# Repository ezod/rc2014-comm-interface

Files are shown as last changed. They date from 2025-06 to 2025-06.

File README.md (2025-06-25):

# RC2014 Communication Interface Module

This is a serial communication module for [RC2014](https://rc2014.co.uk/) computers providing an easy way to switch dual serial port connections between RS232, FTDI, and an ESP01 module.

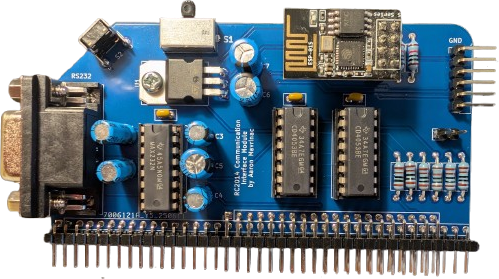
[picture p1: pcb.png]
pcb


| Switch Position | Port A | Port B |
|---|---|---|
| left | FTDI | ESP01  |
| middle | RS232  | ESP01  |
| right | RS232  | FTDI |

These configuration options allow you to switch between a PC and a serial terminal as the main console, connect either to an ESP01 modem using [Zimodem](https://github.com/bozimmerman/Zimodem) or similar, and do XMODEM transfers over FTDI from a serial terminal.

## Bill of Materials

| Reference | Part |
|---|---|
| U1 | LD1117V33 |
| U2 | MAX232N |
| U3-U4 | CD4053B |
| R1-R6 | 1K resistor |
| R7 | 3.3K resistor |
| R8 | 4.7K resistor |
| R9-R10  | 10K resistor |
| C1-C4 | 1uF electrolytic capacitor |
| C5-C6 | 10uF electrolytic capacitor |
| C7 | 47uF electrolytic capacitor |
| C8-C10  | 0.1uF disc/MLCC capacitor |
| S1 | EG2315 DP3T slide switch |
| S2 | right angle tactile switch |
| J1 | 1x6 0.1" right angle pin header  |
| J2 | DE9 female socket |
| J3 | 2x8 0.1" straight pin socket |
| JP1 | 1x2 0.1" straight pin header |
| BUS | 2x40 0.1" right angle pin header |

For the DE9 socket (J2), use [NorComp 182-009-213R561](https://www.digikey.ca/en/products/detail/norcomp-inc/182-009-213R561/1120101) or similar.

This module optionally connects RTS signals to the RS232 and FTDI connectors. If you are using the [Dual Serial Module SIO/2](https://rc2014.co.uk/modules/dual-serial-module-sio2/), to use the RTS signals, you will need to bodge pin 17 (RTSA) of U3 to pin 37 (SPARE1) of the bus, and pin 24 (RTSB) of U3 to pin 38 (SPARE2) of the bus. Otherwise, you can leave R5 and R6 unpopulated.

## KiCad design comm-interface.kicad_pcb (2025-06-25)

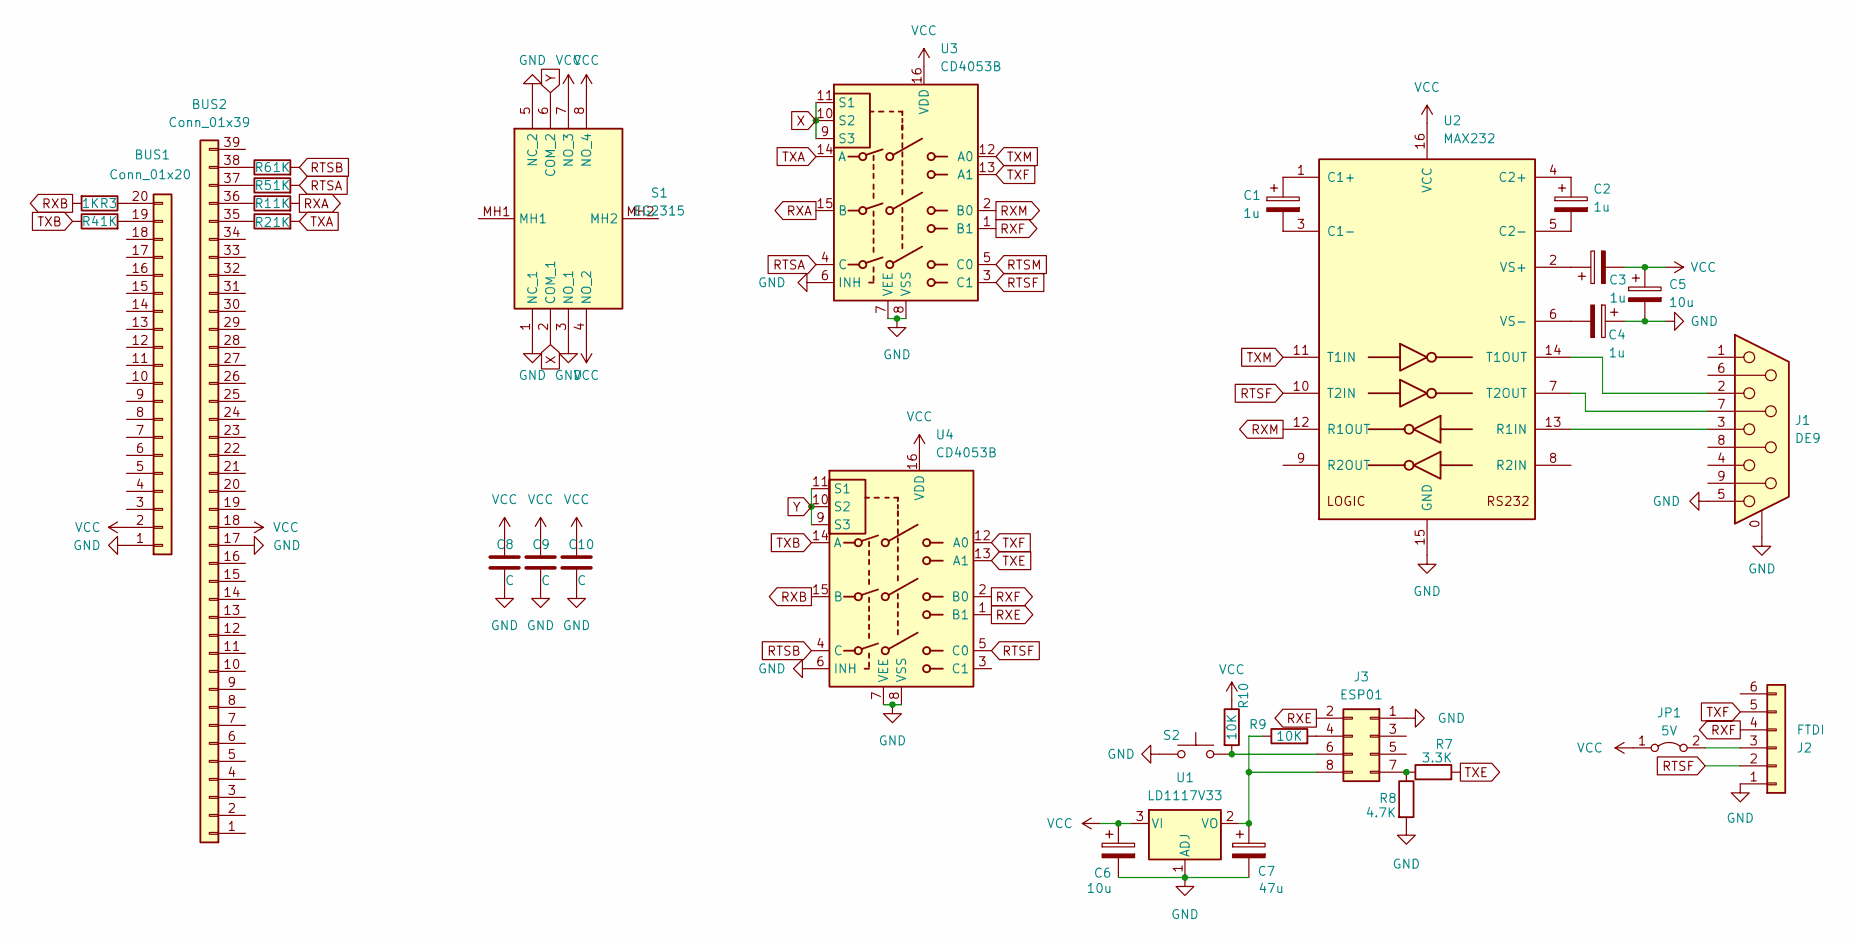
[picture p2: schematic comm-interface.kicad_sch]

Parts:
BUS1: Conn_01x20; PinHeader_1x20_P2.54mm_Vertical
BUS2: Conn_01x39; PinHeader_1x39_P2.54mm_Vertical
C1, C2, C3, C4: 1u; CP_Radial_D4.0mm_P2.00mm
C5, C6: 10u; CP_Radial_D5.0mm_P2.50mm
C7: 47u; CP_Radial_D5.0mm_P2.50mm
C8, C9, C10: C; C_Disc_D5.0mm_W2.5mm_P2.50mm
J1: DE9; DSUB-9_Female_Horizontal_P2.77x2.84mm_EdgePinOffset7.70mm_H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
J2: FTDI; PinHeader_1x06_P2.54mm_Horizontal
J3: ESP01; PinSocket_2x04_P2.54mm_Vertical
JP1: 5V; PinHeader_1x02_P2.54mm_Vertical
R1, R2, R3, R4, R5, R6: 1K; R_Axial_DIN0207_L6.3mm_D2.5mm_P10.16mm_Horizontal
R7: 3.3K; R_Axial_DIN0207_L6.3mm_D2.5mm_P10.16mm_Horizontal
R8: 4.7K; R_Axial_DIN0207_L6.3mm_D2.5mm_P10.16mm_Horizontal
R9, R10: 10K; R_Axial_DIN0207_L6.3mm_D2.5mm_P10.16mm_Horizontal
S1: EG2315; Mouser Part Number 612-EG2315
S2: SW_Push; SW_Tactile_SPST_Angled_PTS645Vx39-2LFS
U1: LD1117V33; TO-220-3_Horizontal_TabDown
U2: MAX232; DIP-16_W7.62mm_Socket
U3, U4: CD4053B; DIP-16_W7.62mm_Socket

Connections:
GND: BUS1.1, BUS2.17, C4.1, C5.2, C6.2, C7.2, C8.2, C9.2, C10.2, J1.0 (PAD), J1.5, J2.1, J3.1, R8.2, S1.1 (NC_1), S1.3 (NO_1), S1.5 (NC_2), S2.1, U1.1 (ADJ), U2.15 (GND), U3.6 (INH), U3.7 (VEE), U3.8 (VSS), U4.6 (INH), U4.7 (VEE), U4.8 (VSS)
unnamed: BUS1.19, R4.2
unnamed: BUS1.20, R3.1
unnamed: BUS2.35, R2.1
unnamed: BUS2.36, R1.1
unnamed: BUS2.37, R5.1
unnamed: BUS2.38, R6.1
unnamed: J2.3, JP1.2 (B)
unnamed: J3.4, R9.2
unnamed: J3.6, R10.2, S2.2
unnamed: J3.7, R7.1, R8.1
unnamed: C7.1, J3.8, R9.1, U1.2 (VO)
unnamed: C1.1, U2.1 (C1+)
unnamed: C1.2, U2.3 (C1-)
unnamed: C2.1, U2.4 (C2+)
unnamed: C2.2, U2.5 (C2-)
unnamed: J1.3, U2.13 (R1IN)
unnamed: J1.2, U2.14 (T1OUT)
unnamed: J1.7, U2.7 (T2OUT)
unnamed: C3.1, U2.2 (VS+)
unnamed: C4.2, U2.6 (VS-)
RTSA: R5.2, U3.4 (C)
RTSB: R6.2, U4.4 (C)
RTSF: J2.2, U2.10 (T2IN), U3.3 (C1), U4.5 (C0)
RTSM: U3.5 (C0)
RXA: R1.2, U3.15 (B)
RXB: R3.2, U4.15 (B)
RXE: J3.2, U4.1 (B1)
RXF: J2.4, U3.1 (B1), U4.2 (B0)
RXM: U2.12 (R1OUT), U3.2 (B0)
TXA: R2.2, U3.14 (A)
TXB: R4.1, U4.14 (A)
TXE: R7.2, U4.13 (A1)
TXF: J2.5, U3.13 (A1), U4.12 (A0)
TXM: U2.11 (T1IN), U3.12 (A0)
VCC: BUS1.2, BUS2.18, C3.2, C5.1, C6.1, C8.1, C9.1, C10.1, JP1.1 (A), R10.1, S1.4 (NO_2), S1.7 (NO_3), S1.8 (NO_4), U1.3 (VI), U2.16 (VCC), U3.16 (VDD), U4.16 (VDD)
X: S1.2 (COM_1), U3.9 (S3), U3.10 (S2), U3.11 (S1)
Y: S1.6 (COM_2), U4.9 (S3), U4.10 (S2), U4.11 (S1)

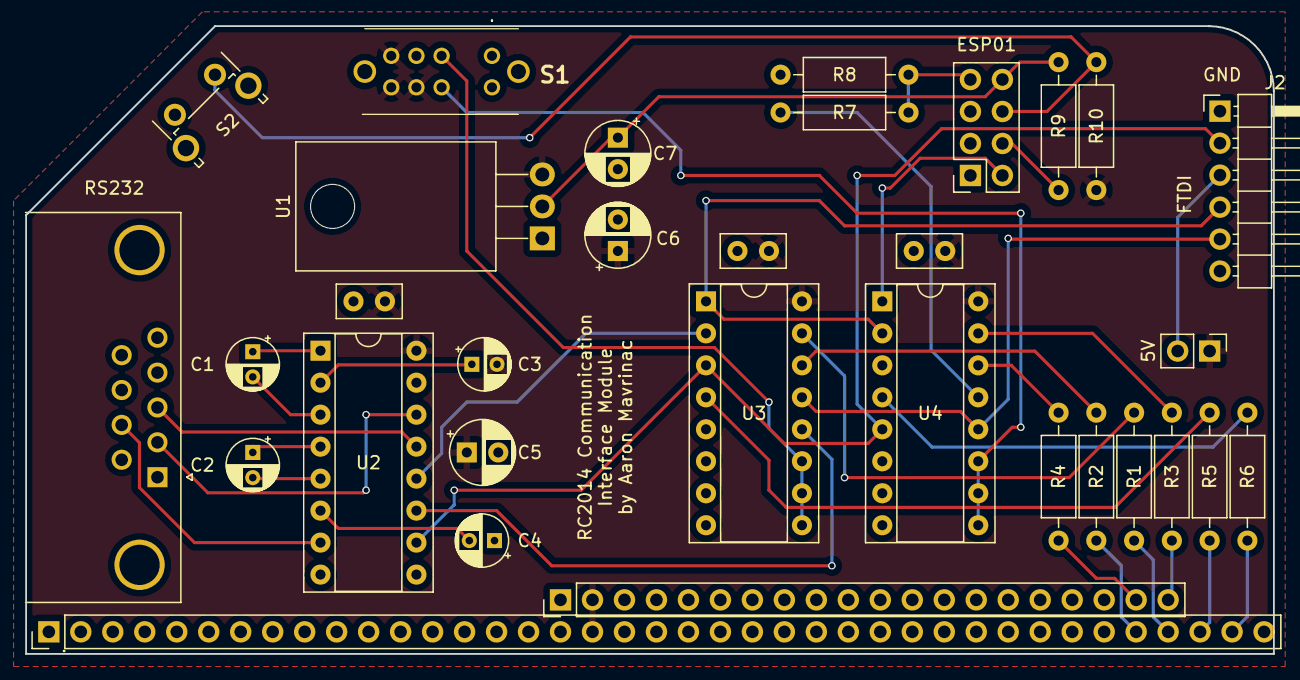
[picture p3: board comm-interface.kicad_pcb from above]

Board: 2 copper layers, 99.1 x 49.9 mm, 32 parts (0 on the bottom side), 37 nets.

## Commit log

2025-06-25 Initial import of KiCad project and gerbers.
    [comm-interface-B_Cu.gbl, comm-interface-B_Mask.gbs, comm-interface-B_Silkscreen.gbo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]
2025-06-25 Crop PCB image.
